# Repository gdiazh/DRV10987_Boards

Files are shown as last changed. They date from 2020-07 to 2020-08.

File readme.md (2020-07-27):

# DRV10987 Boards
Different custom appication eagle-boards for drv10987 BLDC motor driver

## Brief

* DRV10987: PC104-board application using a single driver and atmega328 uC
* DRV10987_SAMD21uC: PC104-board application using three drivers and samd21 uC
* mini_v1: small square board using a single driver and atmega328 uC
* mini_v2: small circle board for a single driver
* mini_v2: small circle board for a single driver
* uC_mini_v2: atmega328 uC mini-circular board
* uCsamd21_mini: samd21 uC mini-circular board

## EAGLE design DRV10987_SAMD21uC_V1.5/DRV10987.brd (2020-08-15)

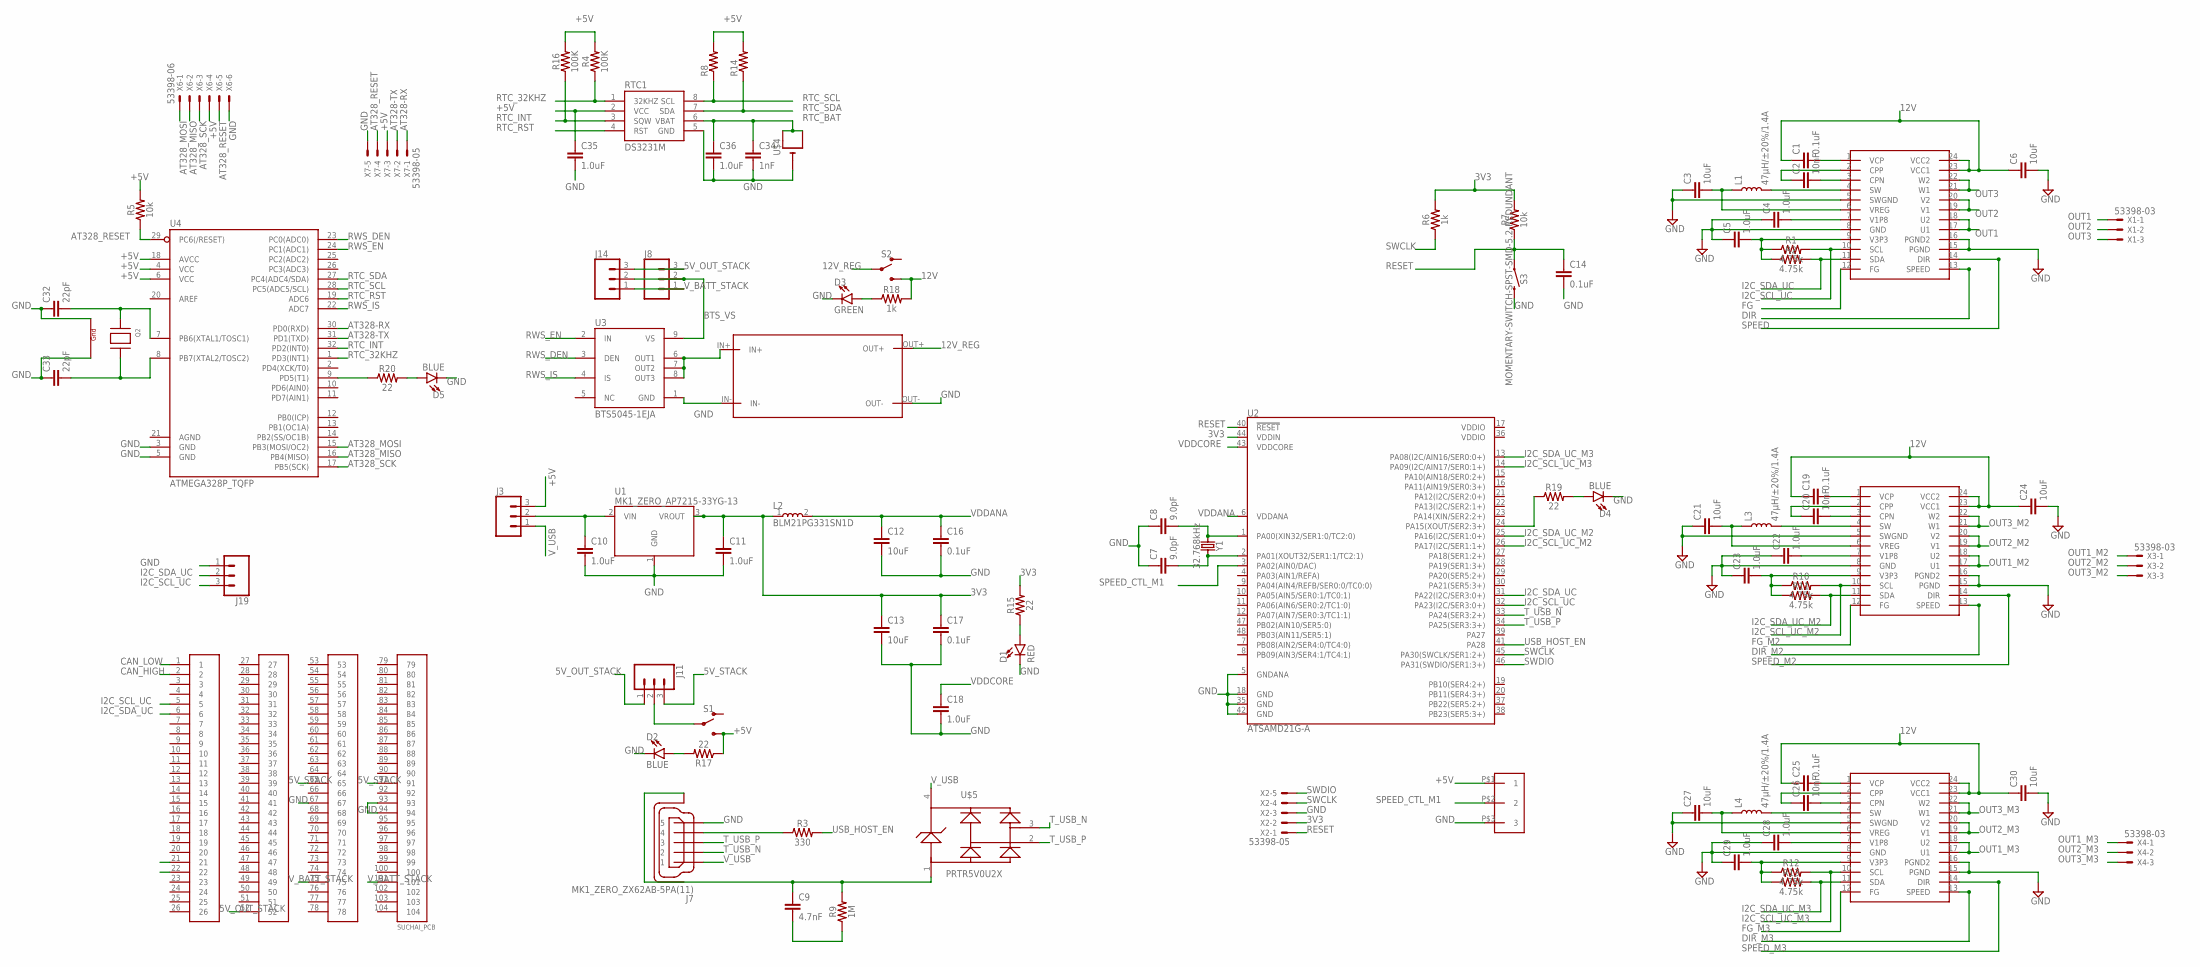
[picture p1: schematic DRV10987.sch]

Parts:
C1, C14, C16, C17, C19, C25: 0.1uF; 0805
C2, C20, C26: 10nF; 0805
C3, C6, C12, C13, C21, C24, C27, C30: 10uF; 0805
C4, C5, C10, C11, C18, C22, C23, C28, C29: 1.0uF; 0805
C7, C8: 9.0pF; 0603
C9: 4.7nF; 0603
C32, C33: 22pF; 0603
C34: 1nF; 0603
C35, C36: 1.0uF; 0402
D1: RED; LED-0603
D2, D4, D5: BLUE; LED-0603
D3: GREEN; LED-0603
J1: SUCHAI_PCB
J3: CONN_03LOCK_LONGPADS; 1X03_LOCK_LONGPADS
J7: MK1_ZERO_ZX62AB-5PA(11); MK1_ZERO_USBMICRO-ZX62-AB-5PA
J8, J11, J14, J19: CONN_03LOCK; 1X03_LOCK
L1, L3, L4: 47µH/±20%/1.4A; SRN6045
L2: BLM21PG331SN1D; INDC2012X87
Q2: XTAL-4-3225; NX3225
R1, R2, R10, R11, R12, R13: 4.75k; 0805
R3: 330; 0603
R4, R16: 100K; 0402
R5, R7: 10k; 0603
R6, R18: 1k; 0603
R8, R14: R-US_R0402; R0402
R9: 1M; 0603
R15, R17, R19, R20: 22; 0603
RTC1: DS3231M; SO08
S1, S2: SWITCH-SPDT-PTH-11.6X4.0MM; SWITCH_SPDT_PTH_11.6X4.0MM
S3: MOMENTARY-SWITCH-SPST-SMD-5.2-REDUNDANT; TACTILE_SWITCH_SMD_5.2MM
U1: MK1_ZERO_AP7215-33YG-13; MK1_ZERO_SOT150P400X160-3N
U2: ATSAMD21G-A; TQFP-48
U3: BTS5045-1EJA; SOIC127P600X170-9N
U4: ATMEGA328P_TQFP; TQFP32-08
U$1, U$6, U$7: DRV10987
U$2: XL6009E1_MODULE
U$3: CONN_03_SMD_SMALL
U$4: CR1220SMT; CR1220-SMD
U$5: ARDUINO_PRTR5V0U2XB; ARDUINO_SOT143B
X1, X3, X4: 53398-03
X2, X7: 53398-05
X6: 53398-06
Y1: 32.768kHz; CRYSTAL-SMD-3.2X1.5MM

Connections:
3V3: C11.1, C13.1, C17.1, L2.1, R6.2, R7.2, R15.2, U1.3 (VROUT), U2.44 (VDDIN), X2.2
5V_OUT_STACK: J1.52, J8.3, J11.1, J14.3
5V_STACK: J1.65, J1.91, J11.3
12V: C1.1, C6.1, C19.1, C24.1, C25.1, C30.1, R18.2, S2.3 (S), U$1.23 (VCC1), U$1.24 (VCC2), U$6.23 (VCC1), U$6.24 (VCC2), U$7.23 (VCC1), U$7.24 (VCC2)
12V_REG: S2.2, U$2.OUT+
+5V: C35.1, J3.3, R4.2, R5.2, R8.2, R14.2, R16.2, R17.1, RTC1.2 (VCC), S1.3 (S), U4.4 (VCC), U4.6 (VCC), U4.18 (AVCC), U$3.P$1 (1), X6.4, X7.3
AT328-RX: U4.30 (PD0(RXD)), X7.1
AT328-TX: U4.31 (PD1(TXD)), X7.2
AT328_MISO: U4.16 (PB4(MISO)), X6.2
AT328_MOSI: U4.15 (PB3(MOSI/OC2)), X6.1
AT328_RESET: R5.1, U4.29 (PC6(/RESET)), X6.5, X7.4
AT328_SCK: U4.17 (PB5(SCK)), X6.3
BTS_VS: J8.2, J14.2, U3.9 (VS)
CAN_HIGH: J1.2
CAN_LOW: J1.1
DIR: U$1.13 (SPEED)
DIR_M2: U$6.13 (SPEED)
DIR_M3: U$7.13 (SPEED)
FG: U$1.12 (FG)
FG_M2: U$6.12 (FG)
FG_M3: U$7.12 (FG)
GND: C3.1, C4.1, C5.1, C6.2, C7.1, C8.1, C10.2, C11.2, C12.2, C13.2, C14.2, C16.2, C17.2, C18.2, C21.1, C22.1, C23.1, C24.2, C27.1, C28.1, C29.1, C30.2, C32.1, C33.1, C34.2, C35.2, C36.2, D1.C, D2.C, D3.C, D4.C, D5.C, J1.67, J1.93, J1.94, J7.5, J19.1, Q2.2 (G2), Q2.4 (G1), RTC1.5 (GND), S3.3 (2), S3.4 (2), U1.1 (GND), U2.5 (GNDANA), U2.18 (GND), U2.35 (GND), U2.42 (GND), U3.1 (GND), U4.3 (GND), U4.5 (GND), U$1.5 (SWGND), U$1.8 (GND), U$1.15 (PGND), U$1.16 (PGND2), U$2.IN-, U$2.OUT-, U$3.P$3 (3), U$4.-, U$6.5 (SWGND), U$6.8 (GND), U$6.15 (PGND), U$6.16 (PGND2), U$7.5 (SWGND), U$7.8 (GND), U$7.15 (PGND), U$7.16 (PGND2), X2.3, X6.6, X7.5
I2C_SCL_UC: J1.5, J19.3, R1.2, U2.32 (PA23(I2C/SER3:0+)), U$1.10 (SCL)
I2C_SCL_UC_M2: R10.2, U2.26 (PA17(I2C/SER1:1+)), U$6.10 (SCL)
I2C_SCL_UC_M3: R12.2, U2.14 (PA09(I2C/AIN17/SER0:1+)), U$7.10 (SCL)
I2C_SDA_UC: J1.6, J19.2, R2.2, U2.31 (PA22(I2C/SER3:0+)), U$1.11 (SDA)
I2C_SDA_UC_M2: R11.2, U2.25 (PA16(I2C/SER1:0+)), U$6.11 (SDA)
I2C_SDA_UC_M3: R13.2, U2.13 (PA08(I2C/AIN16/SER0:0+)), U$7.11 (SDA)
unnamed: C1.2, U$1.1 (VCP)
unnamed: C2.1, U$1.2 (CPP)
unnamed: C2.2, U$1.3 (CPN)
unnamed: L1.2, U$1.4 (SW)
unnamed: J11.2, S1.2
unnamed: C3.2, L1.1, U$1.6 (VREG)
unnamed: C4.2, U$1.7 (V1P8)
unnamed: C7.2, U2.2 (PA01(XOUT32/SER1:1/TC2:1)), Y1.P$2 (2)
unnamed: C5.2, R1.1, R2.1, U$1.9 (V3P3)
unnamed: C8.2, U2.1 (PA00(XIN32/SER1:0/TC2:0)), Y1.P$1 (1)
unnamed: J7.4, R3.1
unnamed: U3.6 (OUT1), U3.7 (OUT2), U3.8 (OUT3), U$2.IN+
unnamed: C32.2, Q2.1 (X1), U4.7 (PB6(XTAL1/TOSC1))
unnamed: C33.2, Q2.3 (X2), U4.8 (PB7(XTAL2/TOSC2))
unnamed: D1.A, R15.1
unnamed: C9.1, J7.6 (SH), J7.7 (SH), J7.8 (SH), J7.9 (SH), J7.10 (SH), J7.11 (SH), R9.2, U$5.1
unnamed: C9.2, R9.1
unnamed: C10.1, J3.2, U1.2 (VIN)
unnamed: D2.A, R17.2
unnamed: C19.2, U$6.1 (VCP)
unnamed: C20.1, U$6.2 (CPP)
unnamed: C20.2, U$6.3 (CPN)
unnamed: L3.2, U$6.4 (SW)
unnamed: C21.2, L3.1, U$6.6 (VREG)
unnamed: C22.2, U$6.7 (V1P8)
unnamed: C23.2, R10.1, R11.1, U$6.9 (V3P3)
unnamed: C25.2, U$7.1 (VCP)
unnamed: C26.1, U$7.2 (CPP)
unnamed: C26.2, U$7.3 (CPN)
unnamed: L4.2, U$7.4 (SW)
unnamed: C27.2, L4.1, U$7.6 (VREG)
unnamed: C28.2, U$7.7 (V1P8)
unnamed: C29.2, R12.1, R13.1, U$7.9 (V3P3)
unnamed: D3.A, R18.1
unnamed: D4.A, R19.2
unnamed: R19.1, U2.24 (PA15(XOUT/SER2:3+))
unnamed: D5.A, R20.2
unnamed: R20.1, U4.9 (PD5(T1))
OUT1: U$1.17 (U1), U$1.18 (U2), X1.1
OUT1_M2: U$6.17 (U1), U$6.18 (U2), X3.1
OUT1_M3: U$7.17 (U1), U$7.18 (U2), X4.1
OUT2: U$1.19 (V1), U$1.20 (V2), X1.2
OUT2_M2: U$6.19 (V1), U$6.20 (V2), X3.2
OUT2_M3: U$7.19 (V1), U$7.20 (V2), X4.2
OUT3: U$1.21 (W1), U$1.22 (W2), X1.3
OUT3_M2: U$6.21 (W1), U$6.22 (W2), X3.3
OUT3_M3: U$7.21 (W1), U$7.22 (W2), X4.3
RESET: C14.1, R7.1, S3.1, S3.2 (1), U2.40 (!RESET!), X2.1
RTC_32KHZ: R4.1, RTC1.1 (32KHZ), U4.1 (PD3(INT1))
RTC_BAT: C34.1, C36.1, RTC1.6 (VBAT), U$4.+$1 (+), U$4.+$2 (+1)
RTC_INT: R16.1, RTC1.3 (SQW), U4.32 (PD2(INT0))
RTC_RST: RTC1.4 (RST), U4.19 (ADC6)
RTC_SCL: R8.1, RTC1.8 (SCL), U4.28 (PC5(ADC5/SCL))
RTC_SDA: R14.1, RTC1.7 (SDA), U4.27 (PC4(ADC4/SDA))
RWS_DEN: U3.3 (DEN), U4.23 (PC0(ADC0))
RWS_EN: U3.2 (IN), U4.24 (PC1(ADC1))
RWS_IS: U3.4 (IS), U4.22 (ADC7)
SPEED: U$1.14 (DIR)
SPEED_CTL_M1: U2.3 (PA02(AIN0/DAC)), U$3.P$2 (2)
SPEED_M2: U$6.14 (DIR)
SPEED_M3: U$7.14 (DIR)
SWCLK: R6.1, U2.45 (PA30(SWCLK/SER1:2+)), X2.4
SWDIO: U2.46 (PA31(SWDIO/SER1:3+)), X2.5
T_USB_N: J7.2, U2.33 (PA24(SER3:2+)), U$5.3
T_USB_P: J7.3, U2.34 (PA25(SER3:3+)), U$5.2
USB_HOST_EN: R3.2, U2.41 (PA28)
VDDANA: C12.1, C16.1, L2.2, U2.6 (VDDANA)
VDDCORE: C18.1, U2.43 (VDDCORE)
V_BATT_STACK: J1.75, J1.101, J8.1, J14.1
V_USB: J3.1, J7.1, U$5.4

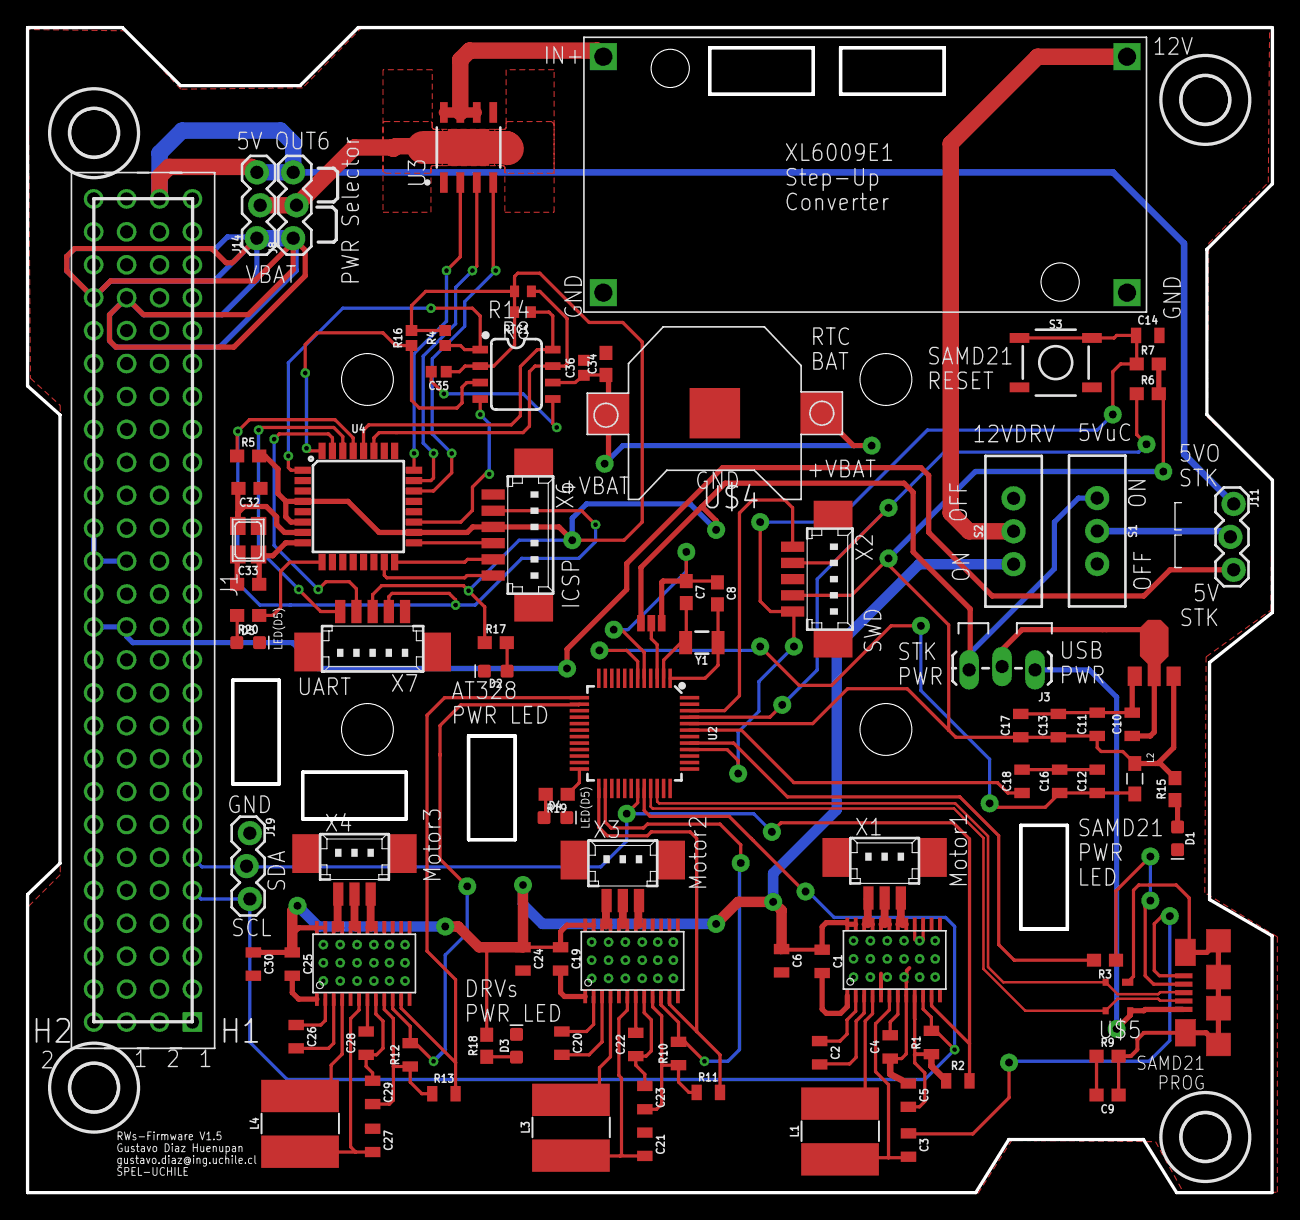
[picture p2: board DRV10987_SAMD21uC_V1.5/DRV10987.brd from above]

Board: 2 copper layers, 96.2 x 90.0 mm, 93 parts (0 on the bottom side), 87 nets.

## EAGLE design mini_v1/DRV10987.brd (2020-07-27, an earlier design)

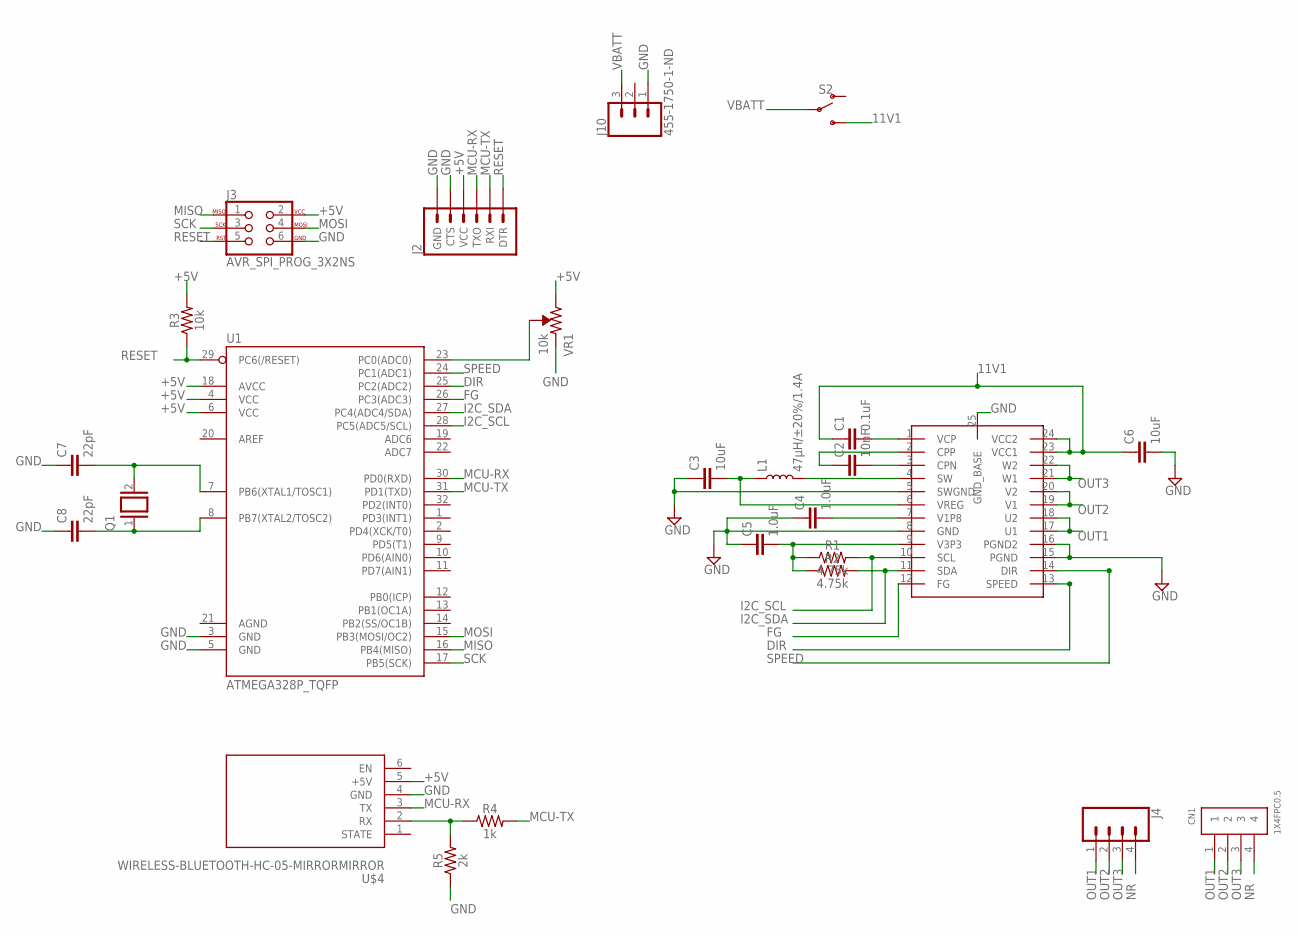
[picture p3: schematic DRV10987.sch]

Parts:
C1: 0.1uF; 0805
C2: 10nF; 0805
C3, C6: 10uF; 0805
C4, C5: 1.0uF; 0805
C7, C8: 22pF; 1206
CN1: 1X4FPC0.5; FPC_0.5MM-4
J2: 6_PIN_SERIAL_TARGET; 1X06
J3: AVR_SPI_PROG_3X2NS; 2X3-NS
J4: CONN_04; 1X04
J10: 455-1750-1-ND; 1X03
L1: 47µH/±20%/1.4A; SRN6045
Q1: XTAL/S; QS
R1, R2: 4.75k; 0805
R3: 10k; 1206
R4: 1k; AXIAL-0.3
R5: 2k; AXIAL-0.3
S2: SWITCH-SPDT-PTH-11.6X4.0MM; SWITCH_SPDT_PTH_11.6X4.0MM
U1: ATMEGA328P_TQFP; TQFP32-08
U$1: DRV10987
U$4: WIRELESS-BLUETOOTH-HC-05-MIRRORMIRROR; WIRELESS-BLUETOOTH-HC-05-MIRROR
VR1: 10k; TRIMPOT-PTH-3386U

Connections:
11V1: C1.1, C6.1, S2.3 (S), U$1.23 (VCC1), U$1.24 (VCC2)
+5V: J2.4 (VCC), J3.2, R3.2, U1.4 (VCC), U1.6 (VCC), U1.18 (AVCC), U$4.5 (+5V), VR1.3 (CW)
DIR: U1.25 (PC2(ADC2)), U$1.13 (SPEED)
FG: U1.26 (PC3(ADC3)), U$1.12 (FG)
GND: C3.1, C4.1, C5.1, C6.2, C7.1, C8.1, J2.5 (CTS), J2.6 (GND), J3.6, J10.1, R5.P$1 (1), U1.3 (GND), U1.5 (GND), U$1.5 (SWGND), U$1.8 (GND), U$1.15 (PGND), U$1.16 (PGND2), U$1.25 (GND_BASE), U$4.4 (GND), VR1.1 (CCW)
I2C_SCL: R1.2, U1.28 (PC5(ADC5/SCL)), U$1.10 (SCL)
I2C_SDA: R2.2, U1.27 (PC4(ADC4/SDA)), U$1.11 (SDA)
MCU-RX: J2.3 (TXO), U1.30 (PD0(RXD)), U$4.3 (TX)
MCU-TX: J2.2 (RXI), R4.P$2 (2), U1.31 (PD1(TXD))
MISO: J3.1, U1.16 (PB4(MISO))
MOSI: J3.4, U1.15 (PB3(MOSI/OC2))
unnamed: C1.2, U$1.1 (VCP)
unnamed: C2.1, U$1.2 (CPP)
unnamed: C2.2, U$1.3 (CPN)
unnamed: L1.2, U$1.4 (SW)
unnamed: C3.2, L1.1, U$1.6 (VREG)
unnamed: C4.2, U$1.7 (V1P8)
unnamed: C7.2, Q1.2, U1.7 (PB6(XTAL1/TOSC1))
unnamed: C5.2, R1.1, R2.1, U$1.9 (V3P3)
unnamed: C8.2, Q1.1, U1.8 (PB7(XTAL2/TOSC2))
unnamed: R4.P$1 (1), R5.P$2 (2), U$4.2 (RX)
unnamed: U1.23 (PC0(ADC0)), VR1.2 (WIPER)
NR: CN1.4, J4.4
OUT1: CN1.1, J4.1, U$1.17 (U1), U$1.18 (U2)
OUT2: CN1.2, J4.2, U$1.19 (V1), U$1.20 (V2)
OUT3: CN1.3, J4.3, U$1.21 (W1), U$1.22 (W2)
RESET: J2.1 (DTR), J3.5, R3.1, U1.29 (PC6(/RESET))
SCK: J3.3, U1.17 (PB5(SCK))
SPEED: U1.24 (PC1(ADC1)), U$1.14 (DIR)
VBATT: J10.3, S2.2

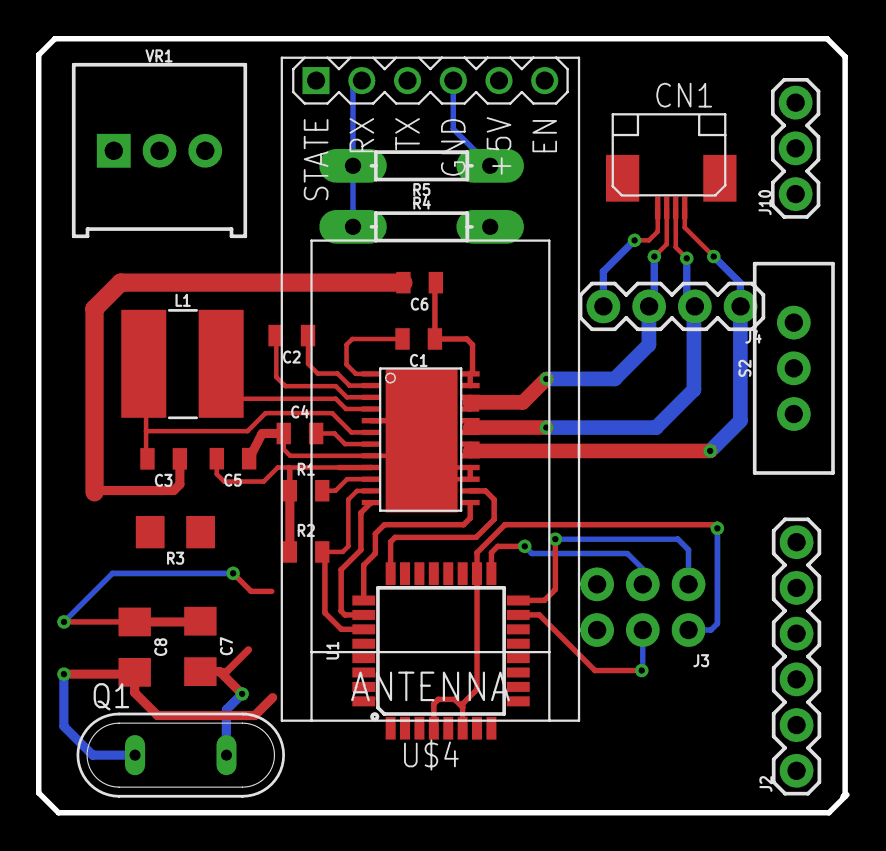
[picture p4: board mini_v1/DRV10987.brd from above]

Board: 2 copper layers, 44.8 x 43.0 mm, 25 parts (0 on the bottom side), 30 nets.

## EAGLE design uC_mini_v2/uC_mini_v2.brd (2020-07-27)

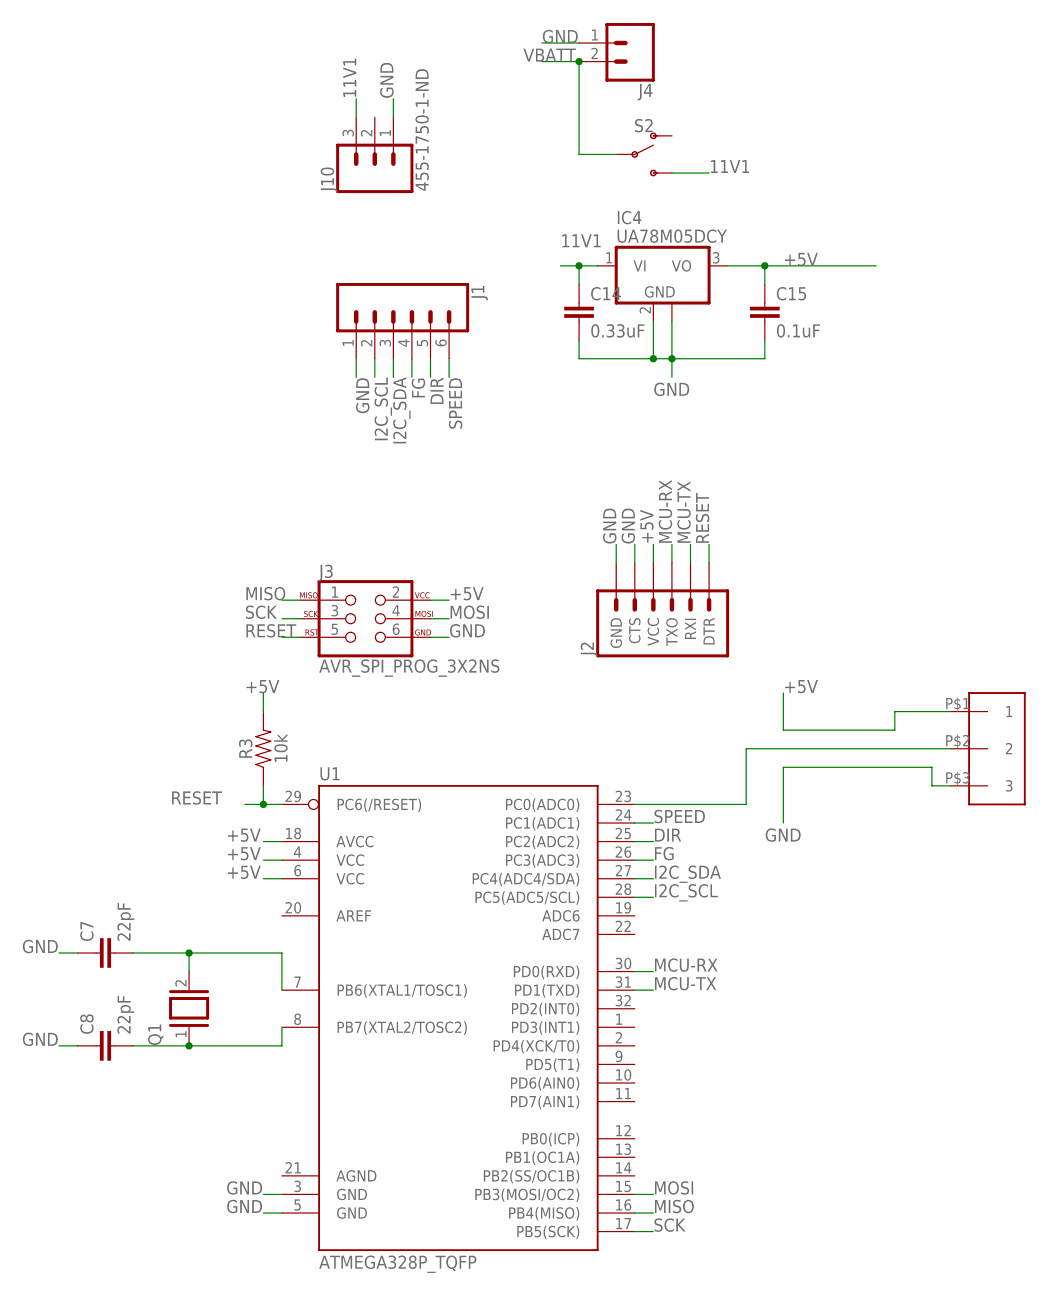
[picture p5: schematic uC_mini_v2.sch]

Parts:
C7, C8: 22pF; 1206
C14: 0.33uF; 1206
C15: 0.1uF; 1206
IC4: UA78M05DCY; SOT223
J1: CONN_06LOCK; 1X06_LOCK
J2: 6_PIN_SERIAL_TARGET; 1X06
J3: AVR_SPI_PROG_3X2NS; 2X3-NS
J4: CONN_02LOCK; 1X02_LOCK
J10: 455-1750-1-ND; 1X03
Q1: XTAL/S; QS
R3: 10k; 1206
S2: SWITCH-SPDT-PTH-11.6X4.0MM; SWITCH_SPDT_PTH_11.6X4.0MM
U1: ATMEGA328P_TQFP; TQFP32-08
U$3: CONN_03_SMD_SMALL

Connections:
11V1: C14.1, IC4.1 (VI), J10.3, S2.3 (S)
+5V: C15.1, IC4.3 (VO), J2.4 (VCC), J3.2, R3.2, U1.4 (VCC), U1.6 (VCC), U1.18 (AVCC), U$3.P$1 (1)
DIR: J1.5, U1.25 (PC2(ADC2))
FG: J1.4, U1.26 (PC3(ADC3))
GND: C7.1, C8.1, C14.2, C15.2, IC4.2 (GND), IC4.4 (GND), J1.1, J2.5 (CTS), J2.6 (GND), J3.6, J4.1, J10.1, U1.3 (GND), U1.5 (GND), U$3.P$3 (3)
I2C_SCL: J1.2, U1.28 (PC5(ADC5/SCL))
I2C_SDA: J1.3, U1.27 (PC4(ADC4/SDA))
MCU-RX: J2.3 (TXO), U1.30 (PD0(RXD))
MCU-TX: J2.2 (RXI), U1.31 (PD1(TXD))
MISO: J3.1, U1.16 (PB4(MISO))
MOSI: J3.4, U1.15 (PB3(MOSI/OC2))
unnamed: C7.2, Q1.2, U1.7 (PB6(XTAL1/TOSC1))
unnamed: C8.2, Q1.1, U1.8 (PB7(XTAL2/TOSC2))
unnamed: U1.23 (PC0(ADC0)), U$3.P$2 (2)
RESET: J2.1 (DTR), J3.5, R3.1, U1.29 (PC6(/RESET))
SCK: J3.3, U1.17 (PB5(SCK))
SPEED: J1.6, U1.24 (PC1(ADC1))
VBATT: J4.2, S2.2

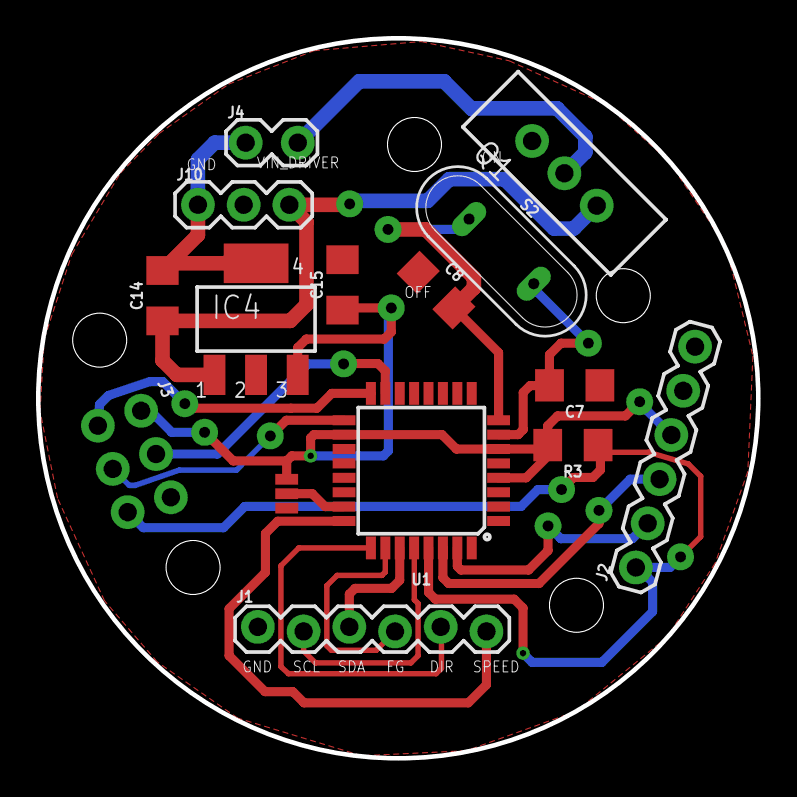
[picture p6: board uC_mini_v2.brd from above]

Board: 2 copper layers, 40.0 x 40.0 mm, 15 parts (0 on the bottom side), 18 nets.

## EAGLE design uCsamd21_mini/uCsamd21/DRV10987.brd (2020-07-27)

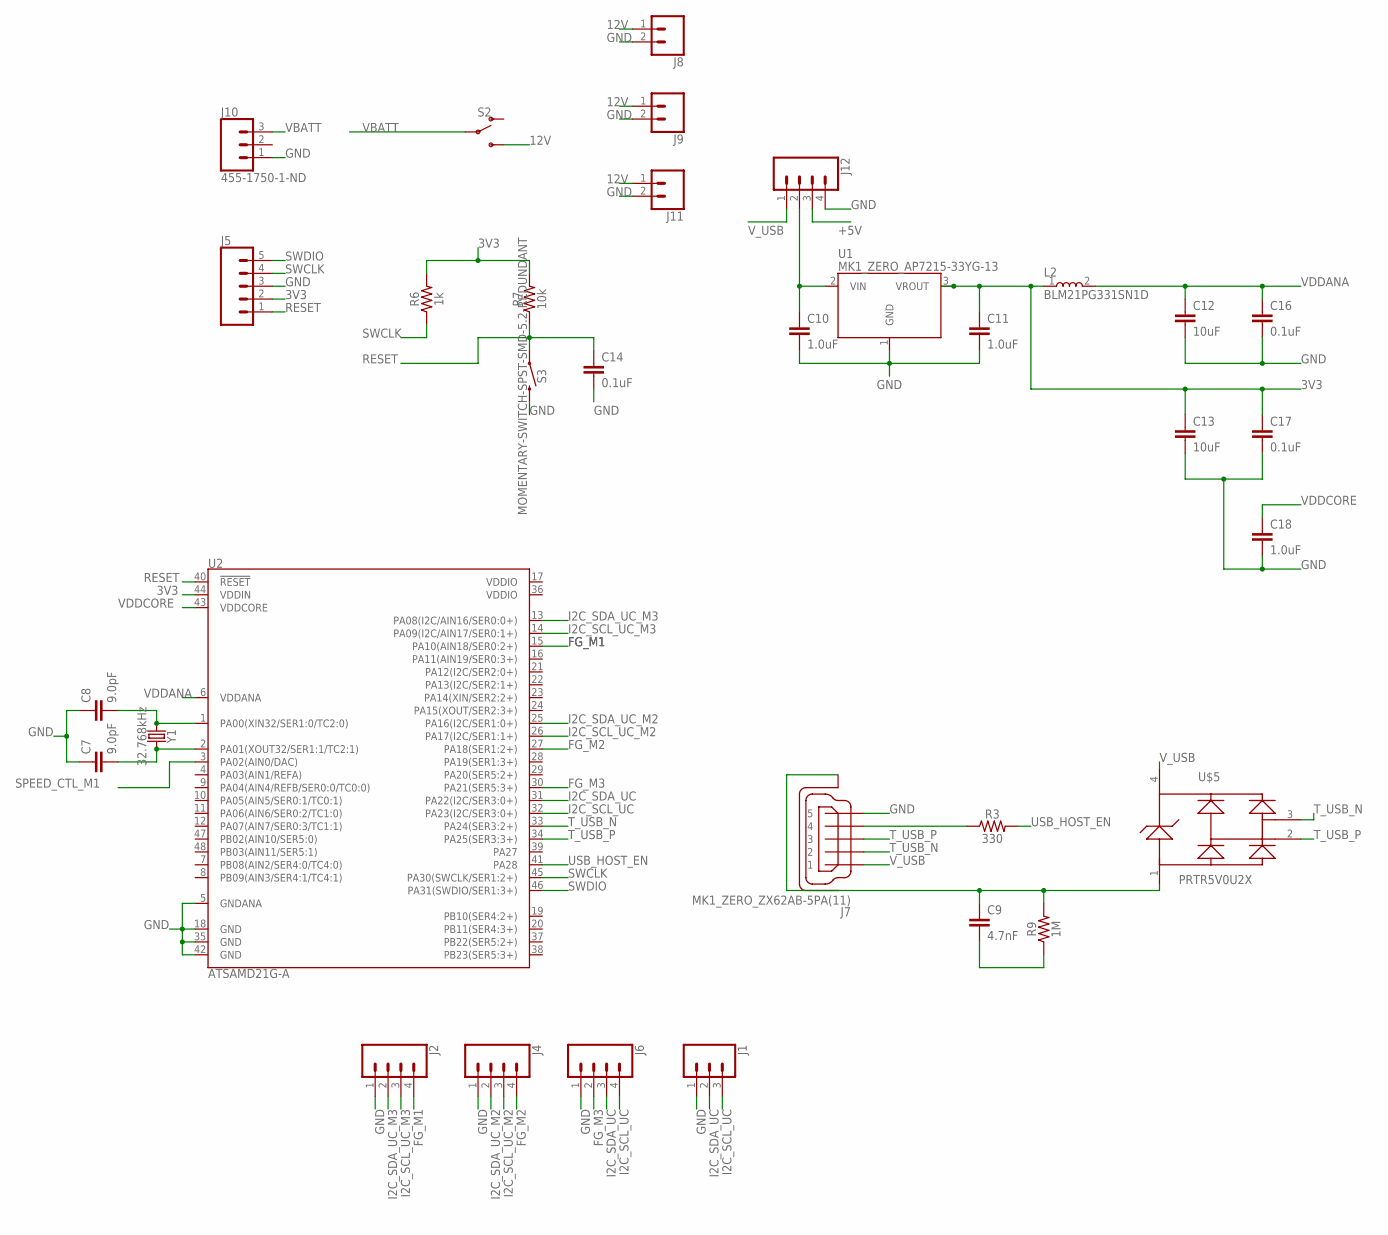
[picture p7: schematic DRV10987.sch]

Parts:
C7, C8: 9.0pF; 0603
C9: 4.7nF; 0603
C10, C11, C18: 1.0uF; 0805
C12, C13: 10uF; 0805
C14, C16, C17: 0.1uF; 0805
J1: CONN_03LOCK; 1X03_LOCK
J2, J4, J6, J12: CONN_04LOCK; 1X04_LOCK
J5: CONN_05LOCK_LONGPADS; 1X05_LOCK_LONGPADS
J7: MK1_ZERO_ZX62AB-5PA(11); MK1_ZERO_USBMICRO-ZX62-AB-5PA
J8, J9, J11: CONN_02LOCK; 1X02_LOCK
J10: 455-1750-1-ND; 1X03
L2: BLM21PG331SN1D; INDC2012X87
R3: 330; 0603
R6: 1k; 0603
R7: 10k; 0603
R9: 1M; 0603
S2: SWITCH-SPDT-PTH-11.6X4.0MM; SWITCH_SPDT_PTH_11.6X4.0MM
S3: MOMENTARY-SWITCH-SPST-SMD-5.2-REDUNDANT; TACTILE_SWITCH_SMD_5.2MM
U1: MK1_ZERO_AP7215-33YG-13; MK1_ZERO_SOT150P400X160-3N
U2: ATSAMD21G-A; TQFP-48
U$5: ARDUINO_PRTR5V0U2XB; ARDUINO_SOT143B
Y1: 32.768kHz; CRYSTAL-SMD-3.2X1.5MM

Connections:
3V3: C11.1, C13.1, C17.1, J5.2, L2.1, R6.2, R7.2, U1.3 (VROUT), U2.44 (VDDIN)
12V: J8.1, J9.1, J11.1, S2.3 (S)
+5V: J12.3
FG_M1: J2.4, U2.15 (PA10(AIN18/SER0:2+))
FG_M2: J4.4, U2.27 (PA18(SER1:2+))
FG_M3: J6.2, U2.30 (PA21(SER5:3+))
GND: C7.1, C8.1, C10.2, C11.2, C12.2, C13.2, C14.2, C16.2, C17.2, C18.2, J1.1, J2.1, J4.1, J5.3, J6.1, J7.5, J8.2, J9.2, J10.1, J11.2, J12.4, S3.3 (2), S3.4 (2), U1.1 (GND), U2.5 (GNDANA), U2.18 (GND), U2.35 (GND), U2.42 (GND)
I2C_SCL_UC: J1.3, J6.4, U2.32 (PA23(I2C/SER3:0+))
I2C_SCL_UC_M2: J4.3, U2.26 (PA17(I2C/SER1:1+))
I2C_SCL_UC_M3: J2.3, U2.14 (PA09(I2C/AIN17/SER0:1+))
I2C_SDA_UC: J1.2, J6.3, U2.31 (PA22(I2C/SER3:0+))
I2C_SDA_UC_M2: J4.2, U2.25 (PA16(I2C/SER1:0+))
I2C_SDA_UC_M3: J2.2, U2.13 (PA08(I2C/AIN16/SER0:0+))
unnamed: J7.4, R3.1
unnamed: C7.2, U2.2 (PA01(XOUT32/SER1:1/TC2:1)), Y1.P$2 (2)
unnamed: C8.2, U2.1 (PA00(XIN32/SER1:0/TC2:0)), Y1.P$1 (1)
unnamed: C9.1, J7.6 (SH), J7.7 (SH), J7.8 (SH), J7.9 (SH), J7.10 (SH), J7.11 (SH), R9.2, U$5.1
unnamed: C9.2, R9.1
unnamed: C10.1, J12.2, U1.2 (VIN)
RESET: C14.1, J5.1, R7.1, S3.1, S3.2 (1), U2.40 (!RESET!)
SPEED_CTL_M1: U2.3 (PA02(AIN0/DAC))
SWCLK: J5.4, R6.1, U2.45 (PA30(SWCLK/SER1:2+))
SWDIO: J5.5, U2.46 (PA31(SWDIO/SER1:3+))
T_USB_N: J7.2, U2.33 (PA24(SER3:2+)), U$5.3
T_USB_P: J7.3, U2.34 (PA25(SER3:3+)), U$5.2
USB_HOST_EN: R3.2, U2.41 (PA28)
VBATT: J10.3, S2.2
VDDANA: C12.1, C16.1, L2.2, U2.6 (VDDANA)
VDDCORE: C18.1, U2.43 (VDDCORE)
V_USB: J7.1, J12.1, U$5.4

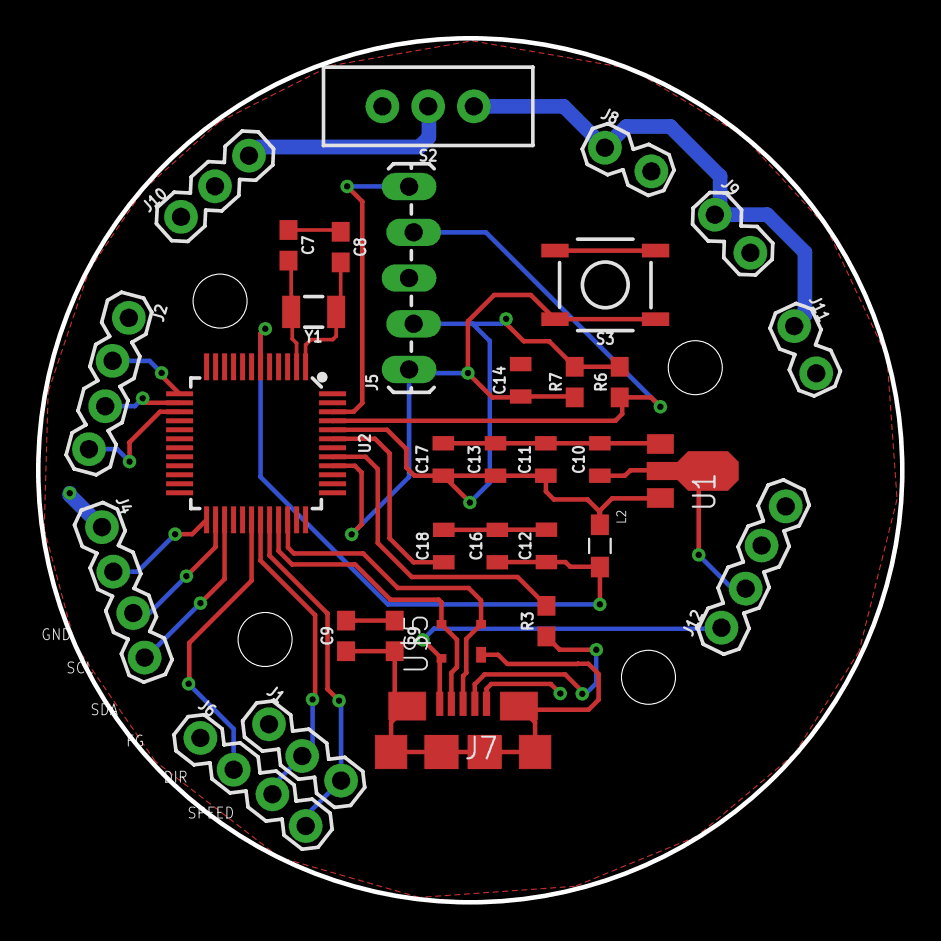
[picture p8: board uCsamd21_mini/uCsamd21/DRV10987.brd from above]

Board: 2 copper layers, 48.0 x 48.0 mm, 33 parts (0 on the bottom side), 28 nets.

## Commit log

2020-08-12 new SAMD21uC_v1.5, added BTS5045, molex connectors, remove conf jumpers, and added holes for wires
    [DRV10987.brd, DRV10987.sch]
2020-08-15 added rtc, atmega328, leds, labels and adjust usb connector
    [DRV10987.brd, DRV10987.sch]

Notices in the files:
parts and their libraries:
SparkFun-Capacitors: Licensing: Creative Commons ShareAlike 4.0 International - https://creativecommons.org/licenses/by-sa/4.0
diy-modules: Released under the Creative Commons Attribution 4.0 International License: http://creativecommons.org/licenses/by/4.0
